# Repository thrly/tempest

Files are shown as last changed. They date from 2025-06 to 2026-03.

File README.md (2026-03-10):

# TEMPEST

a 36/38-key split ergonomic keyboard

 
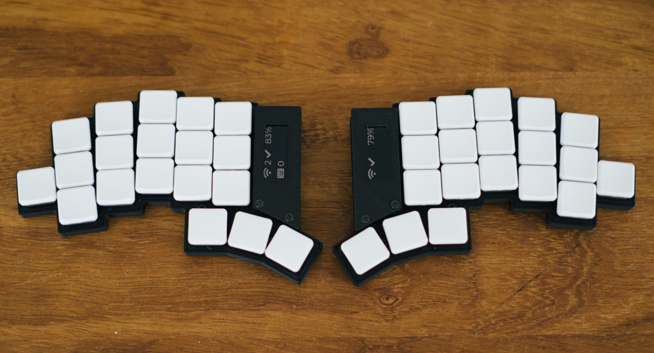
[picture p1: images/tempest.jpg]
Tempest


## Design

- Five columns, three rows, three thumb keys
  - Optional extra key for 36 or 38-key configuration (snap-off pcb)
- Column stagger and splay on the pinky and ring columns
- Powered by nice!nano / pro micro microcontroller
- Optional nice!view display
- Designed for wireless use + battery
- Low profile v1 Choc switches + hotswap sockets
- Reversible PCB
- Uses some components (JST plug, power switch, reset) from the Typeractive Corne design
- Layout designed with [Ergogen](https://ergogen.ceoloide.com/) (see [config.yaml](./ergogen/config.yaml))
- PCB designed with [KiCad](https://www.kicad.org/) (v 9)
- Simple 3D-printable case for both 36 and 38-key layouts

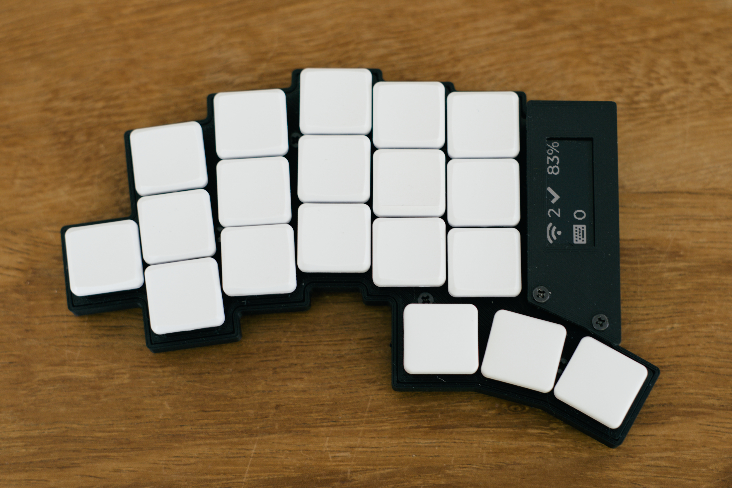
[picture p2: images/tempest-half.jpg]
Tempest


## Firmware

TEMPEST was designed to be used with ZMK. [You can find the ZMK-config repository and a keymap here.](https://github.com/thrly/tempest-zmk)

## Build Guide

[Details on the build and case can be found here.](/build-guide.md)
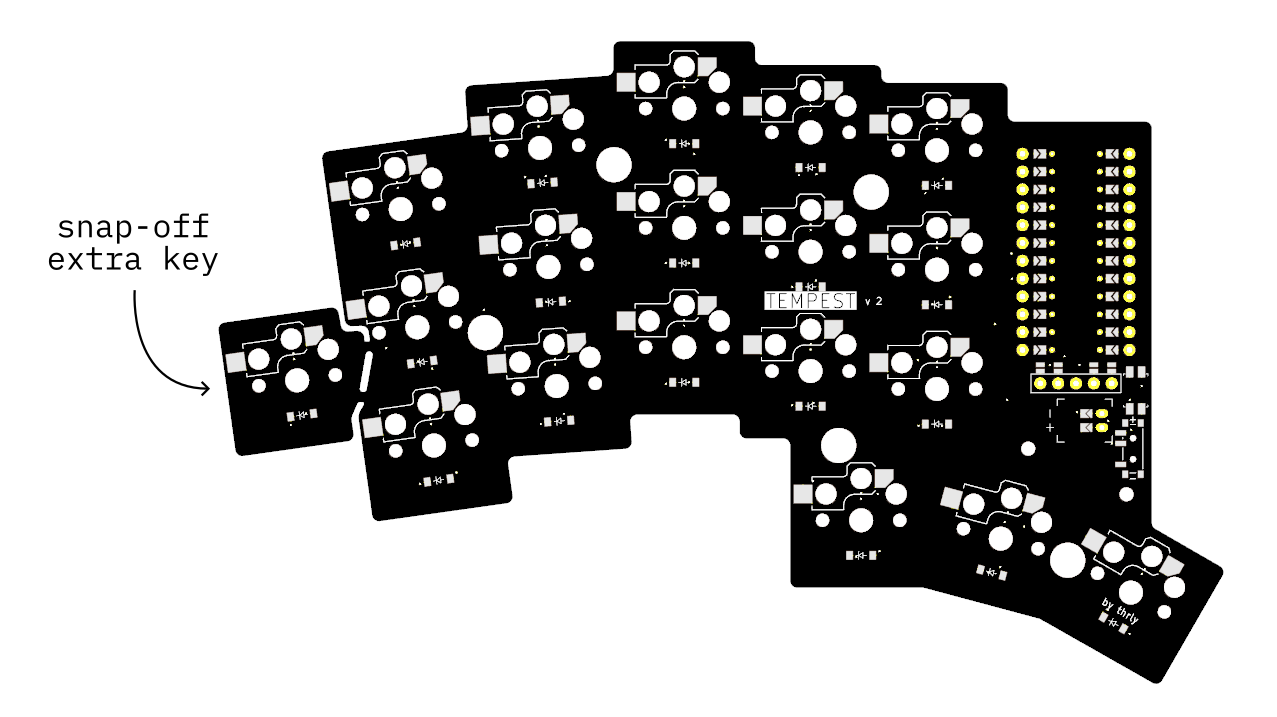
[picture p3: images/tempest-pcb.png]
TEMPEST pcb


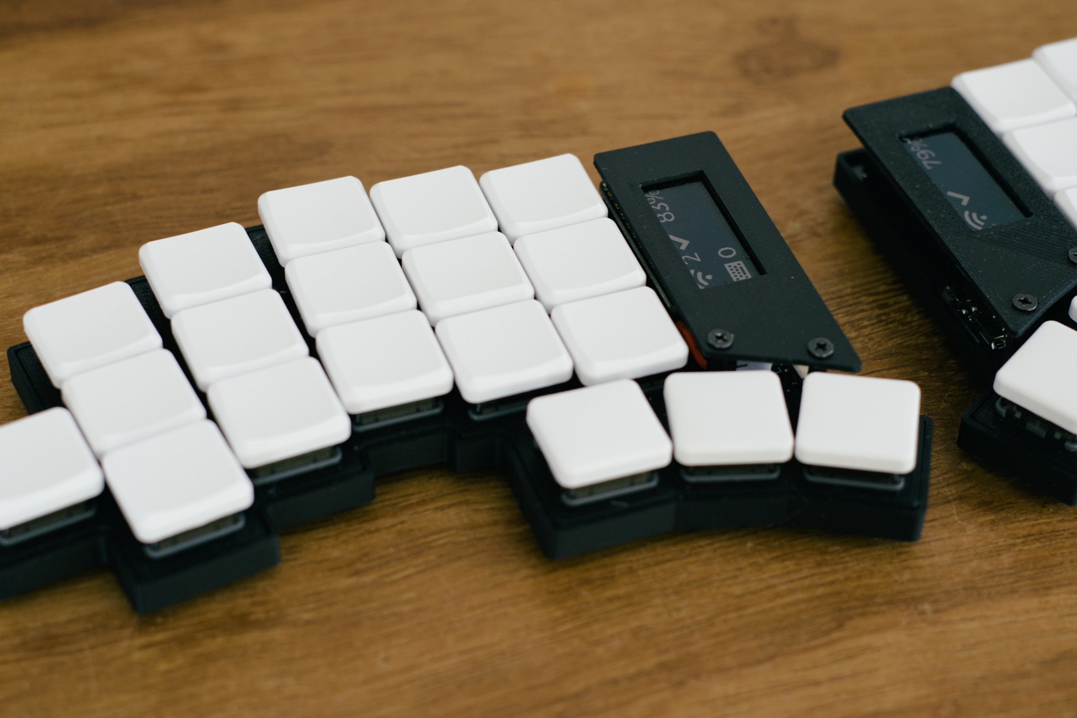
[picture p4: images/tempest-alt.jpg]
Tempest

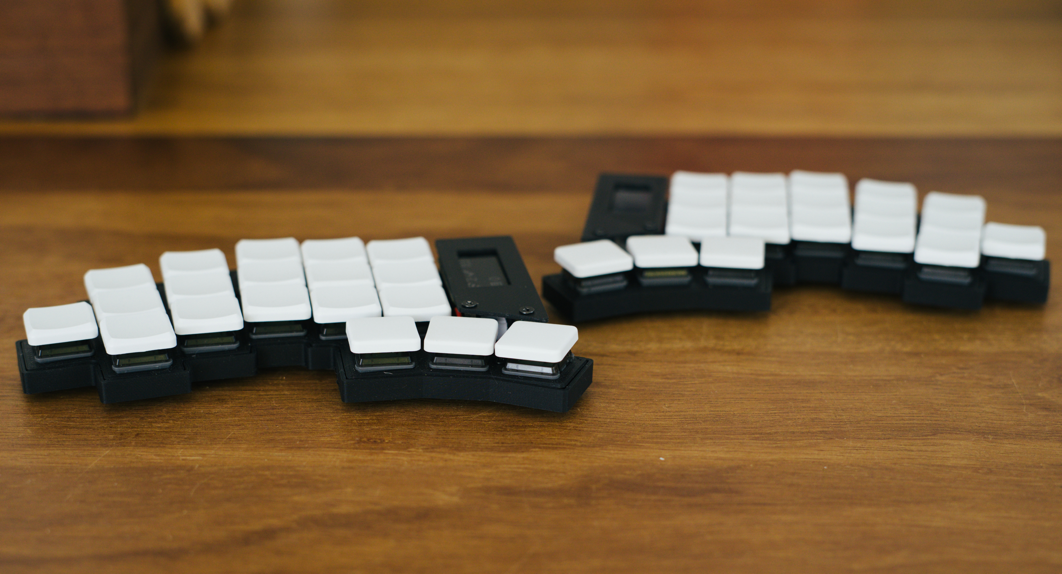
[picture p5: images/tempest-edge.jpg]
Tempest

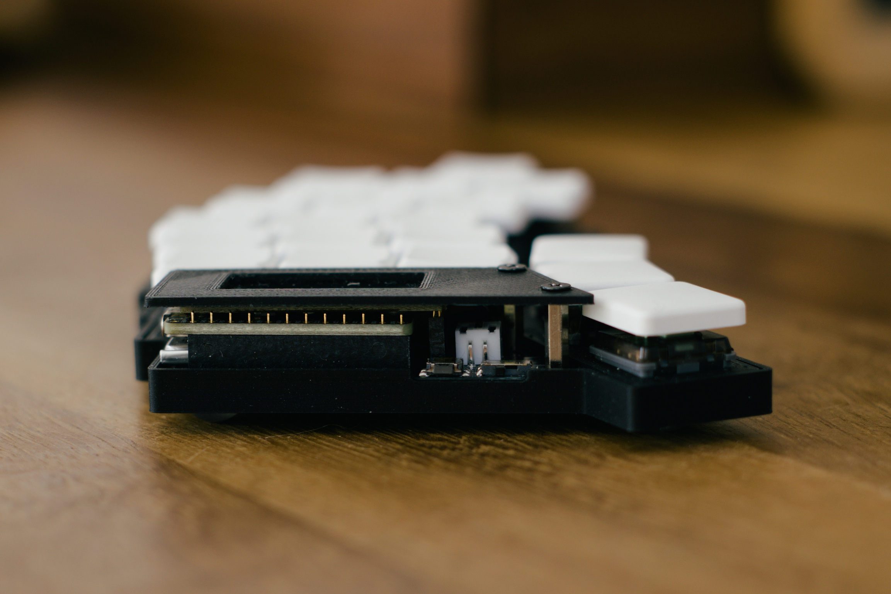
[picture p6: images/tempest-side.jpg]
Tempest


## Influences

TEMPEST is inspired by and takes influence from:

- [Temper](https://github.com/raeedcho/temper) by raeedcho
- [Bad Temper](https://github.com/essFitt/Bad-Temper/tree/main) by essFitt
- [TOTEM](https://github.com/GEIGEIGEIST/TOTEM) by GEIST
- [FORAGER](https://github.com/carrefinho/forager) by carrefinho
- [Corne](https://github.com/foostan/crkbd) by foostan (and the [Typeractive](https://typeractive.xyz/) version)
- also [Chocofi](https://github.com/pashutk/chocofi), [Sweep](https://github.com/davidphilipbarr/Sweep), and others.

## Thanks

If you build Tempest, I'd _love_ to hear how you get on with it. Please say hello via [thrly.com](https://www.thrly.com) or [instagram](https://www.instagram.com/thrly.xy/).

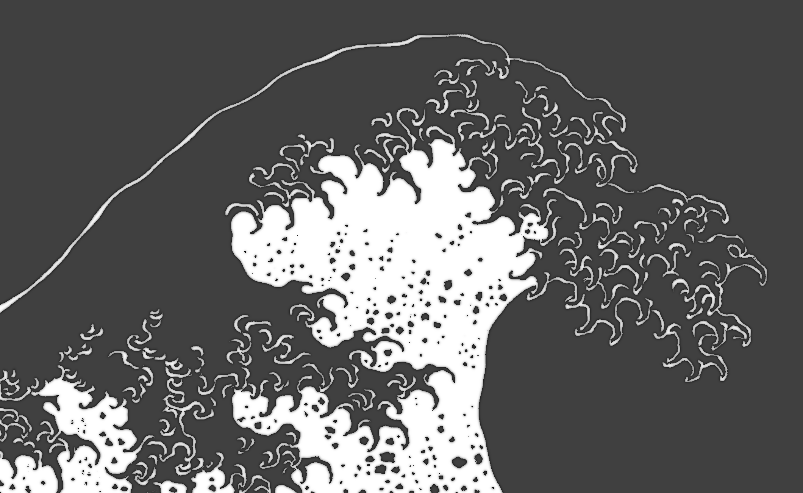
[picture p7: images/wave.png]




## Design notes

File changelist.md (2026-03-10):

# Change list

## V2 major changes

The shape of the pcb has changed slightly in v2:

- optional snap-off pcb for extra key (a la TOTEM) to make 36/38-key layouts
- fixed display connections (currently uses non-standard display pins on the nice!nano, so see the [ZMK config](https://github.com/thrly/tempest-zmk) for pin details)
- slightly less aggressive middle-column stagger (friendlier for `hjkl` on vim!)
- fractionally less offset on thumb-cluster for comfort
- improved spacing on mcu to fix collision with inner key column on the top plate

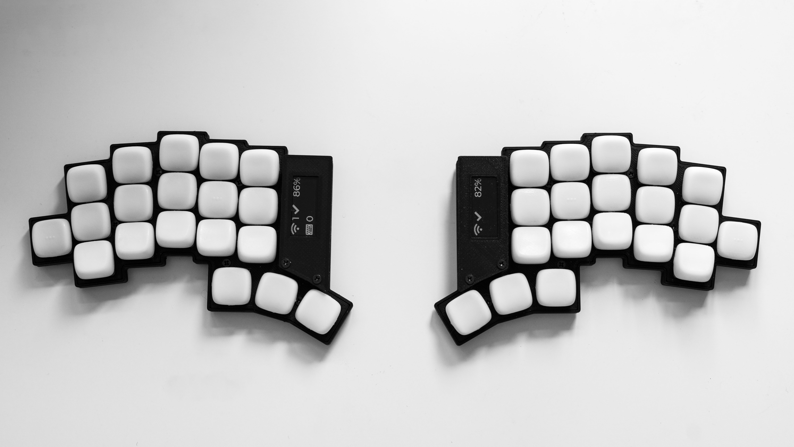
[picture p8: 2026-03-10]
images/tempest-white.jpg

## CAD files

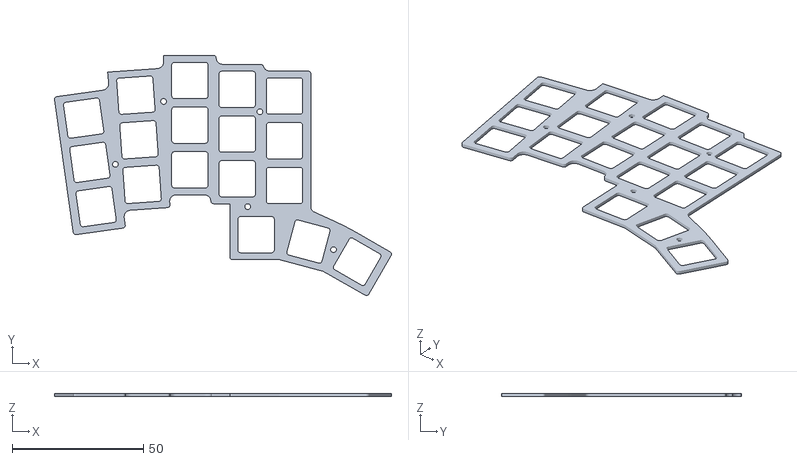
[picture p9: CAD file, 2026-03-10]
case/36-key/tempest-v2-36-key-plate.stl
128.1 x 91.3 x 1.20

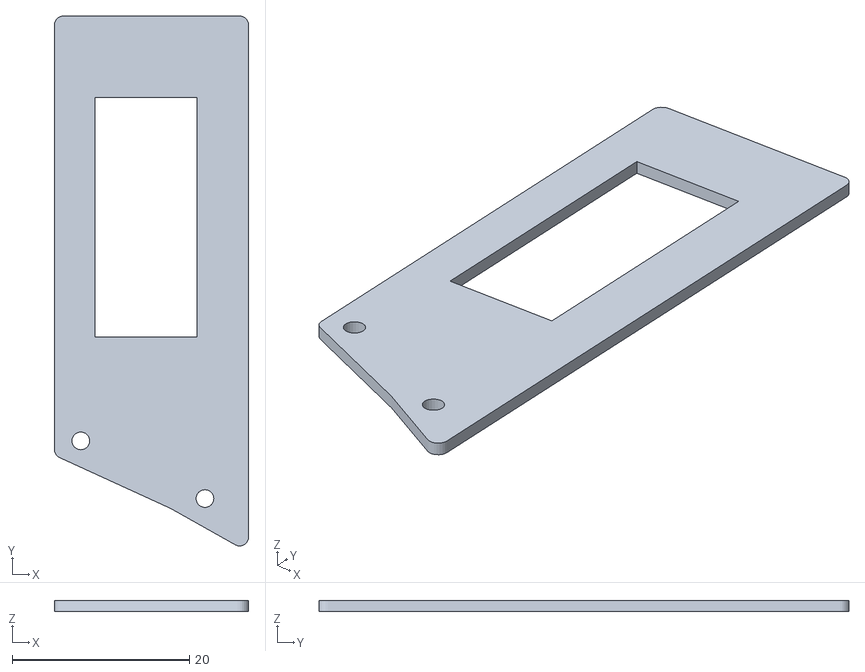
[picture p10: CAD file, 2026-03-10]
case/38-key/tempest-v2-38-key-screen-cover.stl
21.9 x 59.8 x 1.20

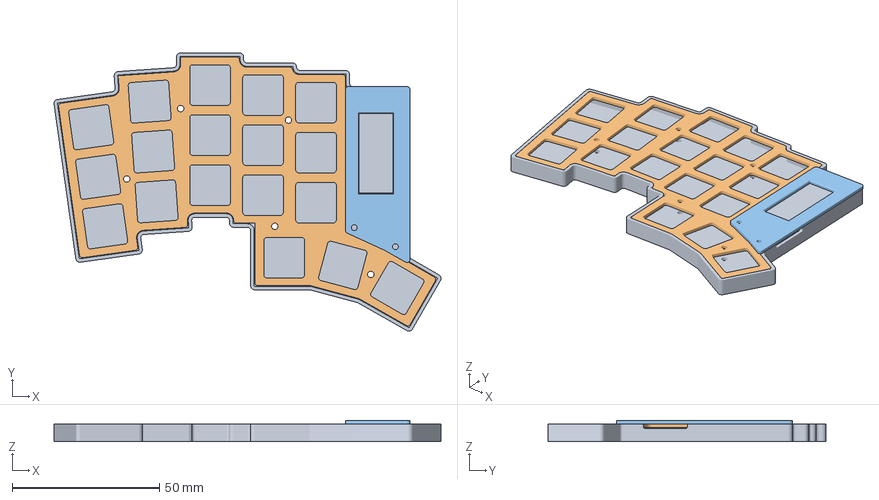
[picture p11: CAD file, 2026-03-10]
case/36-key/tempest-v2-36-key.3mf
131.5 x 94.5 x 7.20 mm
Case
Key Plate
Screen Cover

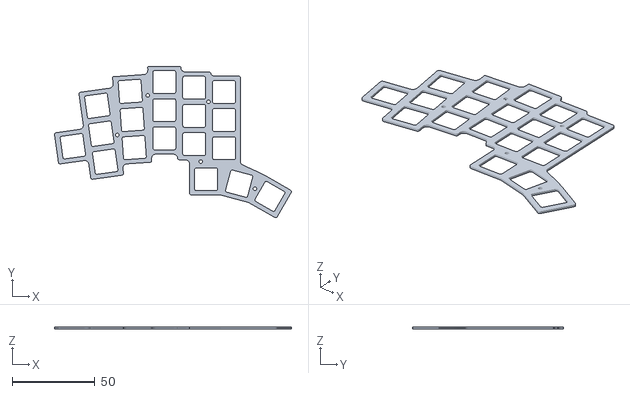
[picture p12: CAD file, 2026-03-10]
case/38-key/tempest-v2-38-key-plate.stl
142.9 x 91.3 x 1.20

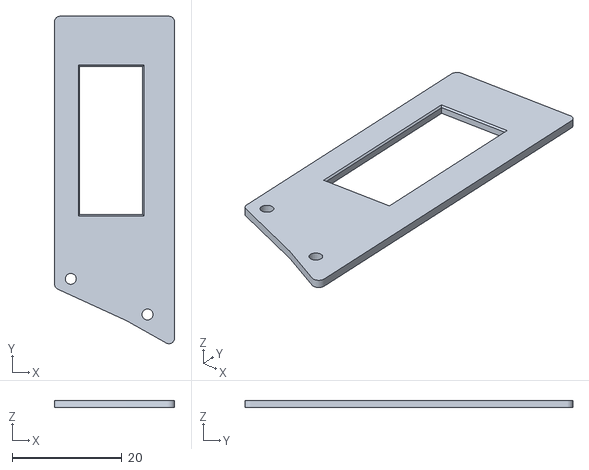
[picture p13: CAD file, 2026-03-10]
case/36-key/tempest-v2-36-key-screen-cover.stl
21.9 x 59.8 x 1.20

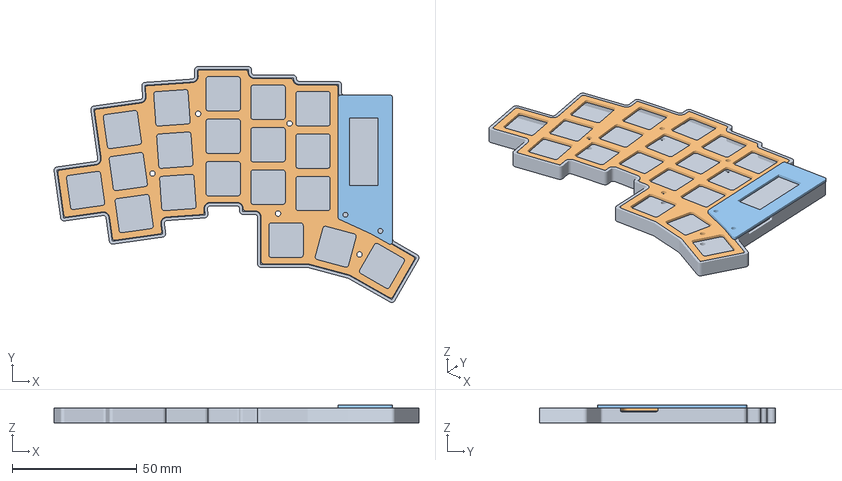
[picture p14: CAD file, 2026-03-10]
case/38-key/tempest-v2-38-key.3mf
146.3 x 94.5 x 7.20 mm
Case
Key Plate
Screen Cover

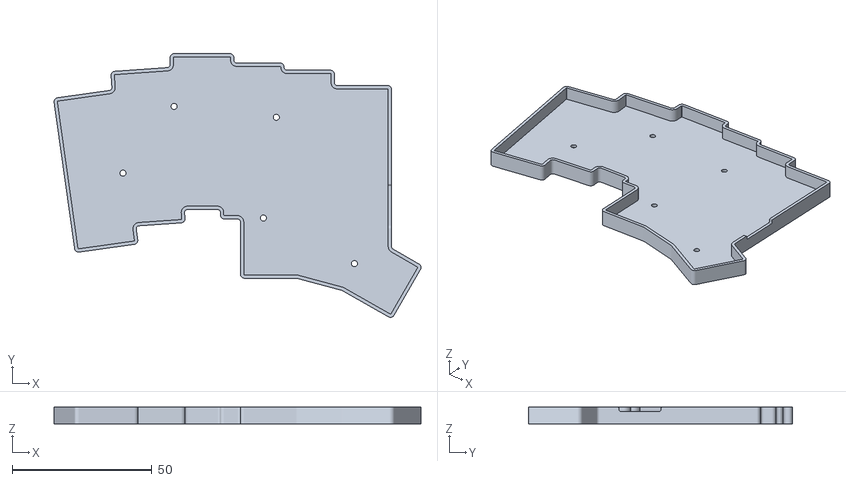
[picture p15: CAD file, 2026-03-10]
case/36-key/tempest-v2-36-key-case.stl
131.5 x 94.5 x 6.00

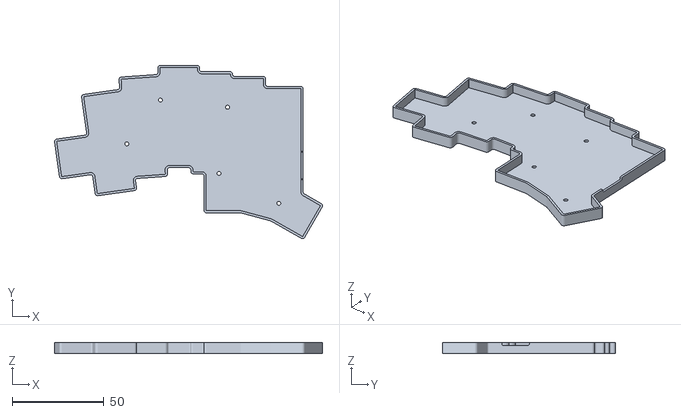
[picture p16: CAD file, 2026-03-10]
case/38-key/tempest-v2-38-key-case.stl
146.3 x 94.5 x 6.00

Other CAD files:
case/36-key/tempest-v2-36-key.f3d
case/38-key/tempest-v2-38-key.f3d

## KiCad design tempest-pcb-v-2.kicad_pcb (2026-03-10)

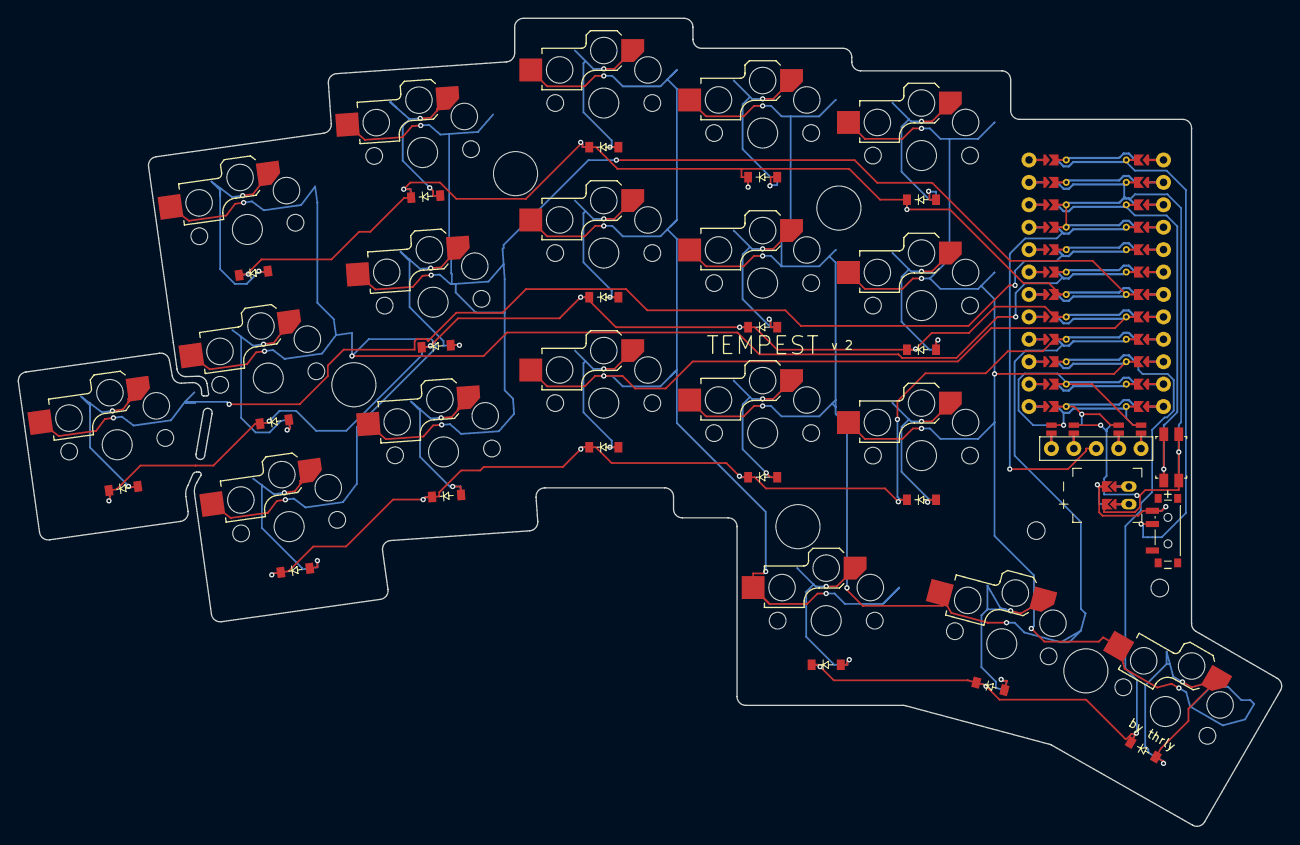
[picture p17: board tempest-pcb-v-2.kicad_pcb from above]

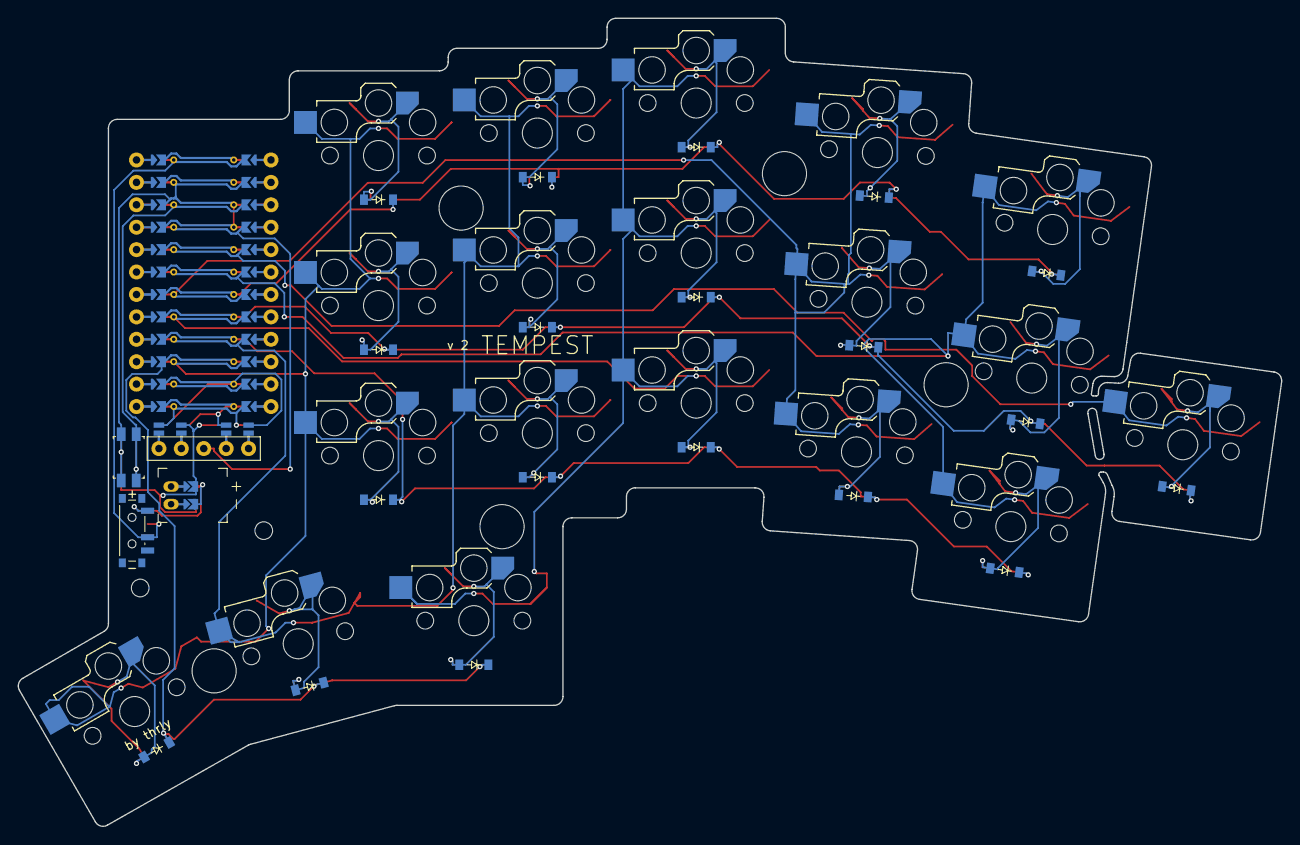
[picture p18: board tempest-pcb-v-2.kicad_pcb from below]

Board: 2 copper layers, 143.2 x 91.6 mm, 50 parts (19 on the bottom side), 43 nets.

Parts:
D1, D2, D3, D4, D5, D6, D7, D8, D9, D10, D11, D12, D13, D14, D15, D16, D17, D18, D19: diode_tht_sod123
DISP1: display_nice_view
JST1: battery_connector_jst_ph_2
MCU1: mcu_nice_nano
MH1, MH2, MH3, MH4, MH5, MH6, MH7: mounting_hole_npth
PWR1: power_switch_smd_side
RST1: reset_switch_smd_side
S1, S2, S3, S4, S5, S6, S7, S8, S9, S10, S11, S12, S13, S14, S15, S16, S17, S18, S19: switch_choc_v1_v2

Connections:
BAT_P: JST1.1, PWR1.1, PWR1.3
CS: DISP1.14, DISP1.24, MCU1.112
DISP1_1: DISP1.1, DISP1.10, DISP1.23
DISP1_2: DISP1.2, DISP1.11, DISP1.22
DISP1_4: DISP1.4, DISP1.12, DISP1.21
DISP1_5: DISP1.5, DISP1.13, DISP1.20
GND: DISP1.15, DISP1.25, JST1.2, MCU1.102, MCU1.121, MCU1.122, RST1.1, RST1.3
JST1_1: JST1.11, JST1.21, JST1.31
JST1_2: JST1.12, JST1.22, JST1.32
MOSI: DISP1.17, DISP1.27, MCU1.114
RAW: MCU1.101, PWR1.2
RST: MCU1.103, RST1.2, RST1.4
SCK: DISP1.16, DISP1.26, MCU1.113
VCC: DISP1.3, MCU1.104
col_extra: MCU1.105, S1.2
col_index: MCU1.109, S11.2, S12.2, S13.2, S18.2
col_inner: MCU1.110, S14.2, S15.2, S16.2, S19.2
col_middle: MCU1.108, S8.2, S9.2, S10.2, S17.2
col_pinky: MCU1.106, S2.2, S3.2, S4.2
col_ring: MCU1.107, S5.2, S6.2, S7.2
extra_home: D1.2, S1.1
far_thumb-cluster: D19.2, S19.1
index_bottom: D11.2, S11.1
index_home: D12.2, S12.1
index_top: D13.2, S13.1
inner_bottom: D14.2, S14.1
inner_home: D15.2, S15.1
inner_top: D16.2, S16.1
mid_thumb-cluster: D18.2, S18.1
middle_bottom: D8.2, S8.1
middle_home: D9.2, S9.1
middle_top: D10.2, S10.1
near_thumb-cluster: D17.2, S17.1
pinky_bottom: D2.2, S2.1
pinky_home: D3.2, S3.1
pinky_top: D4.2, S4.1
ring_bottom: D5.2, S5.1
ring_home: D6.2, S6.1
ring_top: D7.2, S7.1
row_bottom: D2.1, D5.1, D8.1, D11.1, D14.1, MCU1.116
row_home: D1.1, D3.1, D6.1, D9.1, D12.1, D15.1, MCU1.117
row_thumb: D17.1, D18.1, D19.1, MCU1.115
row_top: D4.1, D7.1, D10.1, D13.1, D16.1, MCU1.118

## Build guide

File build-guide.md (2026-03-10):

# Build Guide

The build for the TEMPEST is simple and broadly follows the same steps outlined in [Typeractive's Corne build](https://docs.typeractive.xyz/build-guides/corne-wireless). Theirs is well-written and documented, so read that for now.

Some important notes, however:

Before starting your build, decide if you want the 'extra' outer keys or want the simple 5-column 36-key configuration. If removing the extra keys, simply snap them off the pcb. You may find the break-off points are sharp, so file/sand them down. **WARNING**: the dust from this is toxic, wear a mask and do it outside.

> [!IMPORTANT]
> Microcontroller should be placed **facing DOWN** (i.e. facing the board).

> [!NOTE]
> The microcontroller pin holes on the board have been narrowed (to 0.85mm) to enable the use of no-solder spring headers (MAC8 XB-3-5, as found from [Typeractive](https://typeractive.xyz/products/no-solder-spring-headers?variant=47196312502503)). These headers will fit the nice!nano, but other Pro Micro controllers may have pin holes that are too wide for these spring headers.

> [!IMPORTANT]
> Ensure that you solder the jumper pads for microcontroller, display, and battery plug closed **on the BACK side of the board** (i.e. the same side you're soldering your hotswap switch plugs and diodes).

TEMPEST keyboard

## Bill of Materials (BOM)

| Quantity | Part | Notes |
| --- | --- | --- |
| 2 | TEMPEST PCBs (reversible) from [gerbers .zip file](/tempest%201-1%20gerbers.zip) | order from [JLCPCB](https://jlcpcb.com/) or similar |
| 2 | nice!nano | or other Pro Micro controller (see note about spring headers) |
| 2 | Li-Po battery (110 mAh) | [Typeractive](https://typeractive.xyz/products/lithium-battery-110mah) / [AliExpress](https://www.aliexpress.us/item/3256805162053912.html), see nice!nano documentation for reccomendations, with 2-pin JST plug |
| 2 | 2-pin right-angled JST plug | 2.0mm pin spacing; [AliExpress](https://www.aliexpress.com/item/1005004955655144.html) (NOTE: black seem to be harder to find than white) |
| 2 | Miniature Alps SPDT switch (7 pin) | Power on/off; MSK-12C02 [AliExpress](https://www.aliexpress.com/item/4000685483225.html) (NOTE: if there are two small bumps on the base, you can just slice them off with a knife to sit flush on the PCB) |
| 2 | Miniature momentary button (side mount) | Reset; [AliExpress](https://www.aliexpress.com/item/1005002845025014.html) |
| 4 | 12-pin headers (5mm height) | MAC8 XB-3-5 from [Typeractive](https://typeractive.xyz/products/no-solder-spring-headers?variant=47196312502503) |
| 38* | 1N4148W SMD diodes | SOD-123 package size |
| 38* | Kailh choc switches (v1) |
| 38* | Kailh choc hotswap sockets |
| 38* | Choc keycaps |

\* or 36 if you're snapping off the "extra" outer keys

### Optional: Display

| Quantity | Part | Notes |
| --- | --- | --- |
| 2 | nice!view display |
| 2 | 5-pin header (7mm height) | MAC8 XB-3-7 from [Typeractive](https://typeractive.xyz/products/no-solder-spring-headers?variant=47196312535271) |

### Optional: Case

| Quantity | Part | Notes |
| --- | --- | --- |
| 2 | case .stl | Mirror for right side; PLA; 0.12 mm layer height; >50% infill |
| 2 | key plate STL | Mirror for right side; PLA; 0.12 mm layer height; >50% infill |
| 2 | stick-on rubber feet | or magsafe disc / tenting legs from aliexpress |
| 10 | M2 standoffs | height: 4 mm; diameter: < 5 mm |
| 20 | M2 bolts | height: 4 mm |

## Case

Files for a simple 3D-printed case included [here](/case/). Reccomended to print in Matte PLA, with 0.12 layer height. Infill is not really relevant as the walls are thin.

> [!TIP]
> Alternatively, use the back-plate and top-plate exports from ergogen to order FR-4 plates along with your PCB. You can also use the DXF exports to design your own 3D-printed case/plates easily.

## Ergogen

The ergogen YAML and footprints are contained in the [ergogen](/ergogen/) directory. With the ergogen cli tool installed, use `ergogen .` to build. See [here](https://docs.ergogen.xyz/usage) for guidance.

Ergogen was used mainly as a layout tool for the keys and wiring nets. Some of the footprints for things like MCU, switches, plugs, etc. may have been manually tweaked in the KiCad PCB editor, so don't expect the Ergogen render to be completely the same as the final PCB version.

> [!NOTE]
> Some of the ergogen/ceoloide footprint files used here have been modified slightly from the [originals](https://github.com/ceoloide/ergogen-footprints). Run locally, not on the ergogen web app.

## Ordering the PCB

Use [tempest_v2_gerbers.zip](./tempest-v2-gerbers.zip) for PCB fabrication (i.e. JLPCB, PCBWay).

### Suggested fabrication options

- FR-4 PCB, 1.6 mm
- LeadFree HASL

Latest [KiCad_PCB file](./tempest-pcb-v-2.kicad_pcb) is included, or files can be generated using Ergogen.

TEMPEST PCB Image

> Tempest PCB v2

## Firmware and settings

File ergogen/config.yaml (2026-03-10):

# Ergogen congig file for TEMPEST keyboard

# TEMPEST, by oliver thurley - @thrly
# https://github.com/thrly/tempest
# v1 - spring 2025
# v2 - summer 2025

# invaluable ergogen help from https://flatfootfox.com/ergogen-part1-units-points/

# NOTE: the mcu and display footprint files have been edited to alter drill size to 0.85mm. Build from the footprints on the github repo, not ergogen's web client.

meta:
  engine: 4.1.0
  version: 2.0
  author: oliver thurley
  url: https://github.com/thrly/tempest

units:
  # Proxy Spacing Variables
  kx: cx #choc spaced
  ky: cy
  # Padding Variables
  px: kx + 2
  py: ky + 2

  # vertical offset of mcu area items
  voff: 7

  # pinky splay angles
  spang: 8
  pinksprd: 0.5

  standoff_size: 5 #size for standoff holes on pcb
  screen_standoff_size: 2

  hole1_x: -0.5 kx - 1
  hole1_y: -0.5 ky + 0.5

  hole2_x: -0.52 kx
  hole2_y: -0.35 ky

  hole3_x: 0.5 kx + 1
  hole3_y: 0. ky - 0.5

  hole4_x: 0.5 kx - 5
  hole4_y: -0.5 ky - 2.1

  hole5_x: -0.5 kx - 0.6
  hole5_y: -0.6 ky + 1.5

  wall_thickness: 1.2 # account for the thickness in 3D printed case/plate
  print_fit_tolerance: 0.2 # give the case some overlap beyond pcb

  # display correct choc sizing
  $default_width: 18
  $default_height: 17

points:
  zones:
    matrix:
      anchor.shift: [50, -100] # Fix KiCad placement
      key:
        padding: 1ky # is this extra spacing necessary or will 1 allow spacing for keycaps?
        spread: 1kx
      columns:
        extra: # additional outer key, inspired by TOTEM
          rows.bottom.skip: true
          rows.top.skip: true
          key.splay: spang
          key.column_net: col_extra
        pinky:
          key.stagger: 0.3ky
          # key.splay: spang # comment this line out if using the 'extra' key above
          key.column_net: col_pinky
        ring:
          key.stagger: 0.35ky
          key.splay: -spang/2
          key.spread: 1kx + pinksprd # avoid collision on splayed col?
          key.column_net: col_ring
        middle:
          key.stagger: 0.25ky
          key.splay: -spang/2
          key.spread: 1kx + pinksprd # avoid collision on splayed col?
          key.column_net: col_middle
        index:
          key.stagger: -0.2ky
          key.column_net: col_index
        inner:
          key.stagger: -0.15ky
          key.column_net: col_inner
      rows:
        bottom:
          row_net: row_bottom
        home:
          row_net: row_home
        top:
          row_net: row_top

    thumb:
      key:
        padding: 1ky
        spread: 1kx
      anchor:
        ref: matrix_index_bottom
        shift: [0.4kx, -1.25ky] # this is slightly reduced in v2 from 0.5kx
      columns:
        near:
          key.name: thumb_near
          key.column_net: col_middle
        mid:
          key.splay: -15
          key.origin: [-0.5kx, -0.5ky]
          key.name: thumb_mid
          key.column_net: col_index
        far:
          key.splay: -15
          key.origin: [-0.5kx, -0.5ky]
          key.name: thumb_far
          key.column_net: col_inner
          # # for 1.5 thumb key
          # key.width: 1.5kx
          # key.rotate: 90
      rows:
        thumb-cluster:
          row_net: row_thumb

outlines:
  # just the keys
  raw:
    - what: rectangle
      where: true
      size: [px, py]

  # keys without padding
  keys:
    - what: rectangle
      where: true
      size: [kx-0.5, ky-0.5]

  # keys without padding
  key-plug:
    - what: rectangle
      where: true
      size: [13.8, 13.8]

  mcu:
    - what: rectangle
      where:
        - ref: matrix_inner_top
          shift: [19.5, -20 - voff] # v2 - Creates more space between inner key col and mcu (issue #4)
      size: [22, 62]

  # draw thumb cluster outline
  thumb_outline:
    - what: polygon
      operation: stack
      # bound: true
      points:
        - ref: thumb_near
          shift: [-0.5px, 0.75py]
        - ref: matrix_inner_bottom
          shift: [0.45px, -0.5py]

        - ref: thumb_far
          shift: [-0.5px, 0.5py]
        - ref: thumb_far
          shift: [0.5px, 0.5py]
        - ref: thumb_far
          shift: [0.5px, -0.5py]
        - ref: thumb_far
          shift: [-0.5px, -0.5075py]

        - ref: thumb_near
          shift: [0.5px, -0.5py]
        - ref: thumb_near
          shift: [-0.5px, -0.5py]

  # combine keys with thumb cluster
  key_section: [raw, thumb_outline]
  key_thumb_mcu: [key_section, mcu]

  top_plate_cutouts: [key-plug] #, mcu_key_shave]

  top_plate:
    - name: key_section
      # expand: print_fit_tolerance + wall_thickness
    - operation: subtract
      name: top_plate_cutouts
      fillet: 1

  board_outline:
    - name: key_thumb_mcu
      expand: 0.1 # padding on outer edge or board
      fillet: 1

  back_plate:
    - name: board_outline
      expand: wall_thickness + print_fit_tolerance
      fillet: 1
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

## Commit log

2025-03-26 Add ergogen config with keyboard layout and footprints
2025-03-29 Add M2 mounting holes
2025-03-29 update footprint paths to match online ceoloide generator path footprints
2025-03-31 Changed MCU socket sizes to 0.85mm for no-solder headers
2025-03-31 Edit mounting hole placement
2025-04-01 PCB version 0.01
    [tempest-pcb-v01.kicad_pcb]
2025-04-03 Add DXF and STL for 1.2mm plates and case test
    [tempest case test v01.stl, tempest-back-case+1.2mm.dxf, tempest-back-plate.dxf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]
2025-04-13 Add 0.5mm tolerance fit to plates for better case fit
    [config.yaml]
2025-04-13 Add second case tests, move cases into subfolders
    [tempest case test v01.stl, tempest case test with cutouts.stl, tempest test 2 new fit.stl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]
2025-04-30 Fix error on key column nets. Ring, Mid, and Index weren't properly assigned via variable names (they used pin numbers, which didn't work in Kicad!)
    [config.yaml]
2025-04-30 Change MCU plate spacing area to give more room
2025-05-01 Removed outer pcb padding space. Repositioned mcu area lower.
2025-05-01 Add v1.1 pcb and img, removed v0.1
    [tempest-pcb-v01.kicad_pcb, tempest-pcb-v1-1.kicad_pcb]
2025-05-02 Tidy folder structure, remove v.0.0 pcb and gerbers. Add gerbers zip.
    [tempest case test with cutouts.stl, tempest test 2 new fit.stl, tempest-back-case+1.2mm.dxf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]
2025-06-03 Added note about spring header hole sizing
2025-06-04 Add BOM
2025-06-12 Update wishlist for next version (v 2) with additional design considerations and improvements
    [tempest_pcb_v1.1.kicad_pcb]
2025-06-12 Add 3D printable case for v 1.1 pcb
    [tempest_v1.1_case.stl, tempest_v1.1_top-plate.stl]
2025-08-24 v2 ergogen changes
    [tempest-v2-36-key-case.stl, tempest-v2-36-key-plate.stl, tempest-v2-36-key-screen-cover.stl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]
2025-08-24 Update pcb, gerbers and README for v2
    [tempest-pcb-v-2.kicad_pcb, tempest_pcb_v1.1.kicad_pcb]
